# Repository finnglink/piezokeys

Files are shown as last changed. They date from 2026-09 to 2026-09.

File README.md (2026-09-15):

# PiezoKeys

A 4-key USB-MIDI keyboard using piezo discs for keystroke detection, with a laser-cut faceplate, 3D printed case, and an RGBW LED under each key. It's kinda like a stenographer's keyboard but for music: 4 keys allow you to play 15 different notes, depending on which keys you hit. You can set a root note, scale and transposition (up to +/- 2 octaves) in a small menu. 

<p align="center">
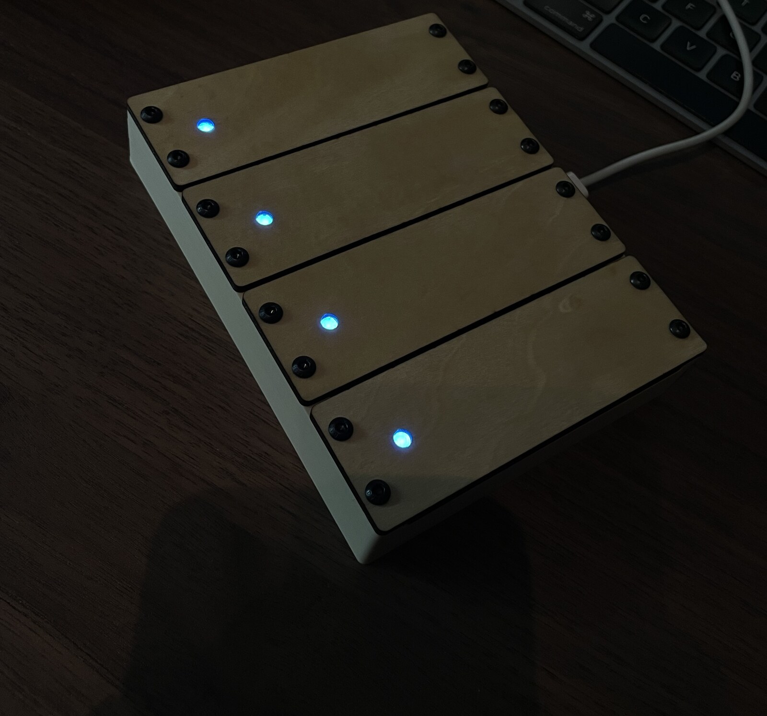
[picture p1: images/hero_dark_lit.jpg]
  
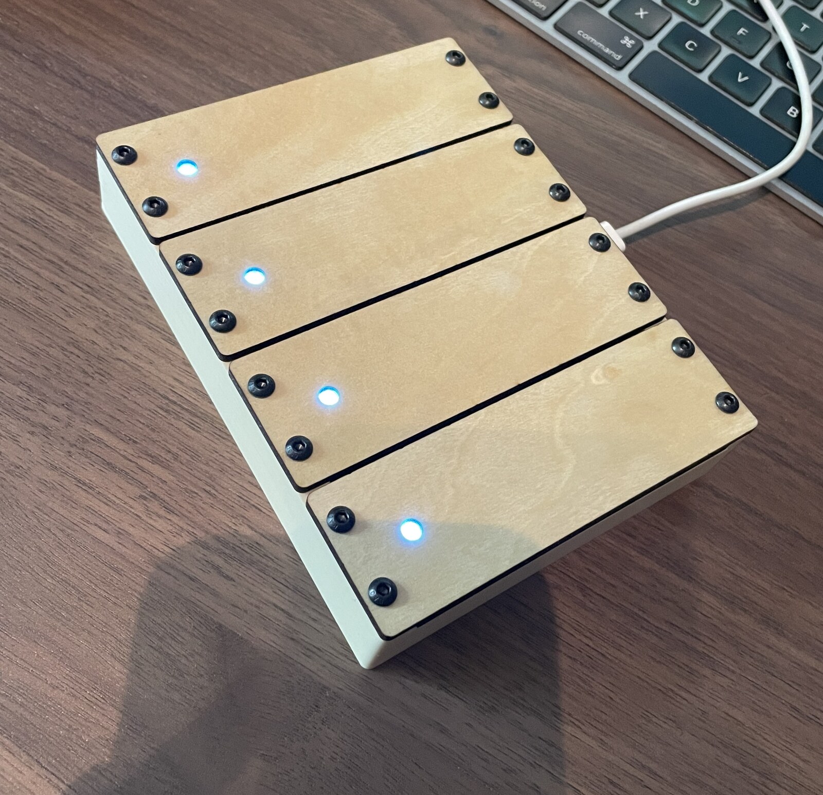
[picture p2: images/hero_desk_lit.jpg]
  
</p>

Runs on a Seeed XIAO RP2040 and shows up as a class-compliant USB MIDI device. You could also easily add a TRS MIDI Out circuit to use it with hardware synths.

### Three things you should know before you build this

**The firmware is AI-written.** I'm not a programmer, I came up with the idea, developed the keystroke and menu logic and designed the 3D models, with Claude Code doing the actual coding. It works and it's been play-tested and tuned for some time, but check the code for yourself instead of blindly trusting, and if you find something dumb, open an issue or a PR.

**Key 1 and Key 4 are less sensitive than 2 and 3.** They sit right against the outer walls of the case, which are stiffer than the inner walls, so the same tap produces a weaker signal. Software compensates with lower trigger thresholds on those two, and it's somewhat fine — but if you want to fix it properly, add one dummy/blank key on each end of the case so 1 and 4 become "inner" keys too. 

**Consider this project a work-in-progress** Some hardware bits are not 100% ideal yet, mentioned further down the build guide. Feel free to fix and improve them yourself, or do a whole different take on this concept. 

Massive credit to [**ellitone.usa**](https://www.instagram.com/ellitone.usa/) on Instagram — this whole project exists because I saw what they were doing with piezos and picked their brain about it. And their stuff looks and sounds even better than mine xD

> [!TIP]
> Join my [Discord Server](https://glnnk.art/discord) for build support and discussion.

---

## Contents

- [Bill of Materials](#bill-of-materials)
- [3D print & laser files](#3d-print--laser-files)
- [Assembly](#assembly)
- [Flashing the firmware](#flashing-the-firmware)
- [How to play it](#how-to-play-it)
- [Prototyping sketch](#prototyping-sketch)
- [License](#license)

---

## Bill of Materials

| Part | Qty | Notes |
|---|---|---|
| [USB-C breakout panel (4 or 6 pin)](https://de.aliexpress.com/item/1005005993405905.html) | 1 | Mounts in the case wall |
| [USB-C plug breakout, **male**](https://de.aliexpress.com/item/1005006026634212.html) | 1 | Remove any resistors on this one — see wiring below |
| [27–28mm piezo disc](https://de.aliexpress.com/item/1005009297969587.html) | 4 | Smaller might work too, haven't tried it |
| [SK6812 RGBW breakout, individual pixel](https://de.aliexpress.com/item/1005001527124508.html) | 4 | A cuttable strip works too, other addressable LEDs probably work with a code tweak |
| M3 heat-press insert | 16 | |
| M3x6mm screw | 16 | Longer is fine, up to 10-12mm |
| M2x6mm screw | 2 | Hold the USB-C panel jack in place |
| M2 standoff or nut | 2 | Hold the USB-C panel jack in place |
| Seeed XIAO RP2040 | 1 | Has USB-C (with MIDI capability) + 4 ADC pins, which you need all of. The RP2350 version only has 3 ADCs and won't work here |
| 620Ω resistor (600–700Ω range fine) | 4 | Pulldown for each piezo. Wider range works but you may need to retune thresholds in firmware or lose velocity sensitivity |
| Felt or rubber feet | 4 | I used 18mm felt pads meant to be put under furniture |

## 3D print & laser files

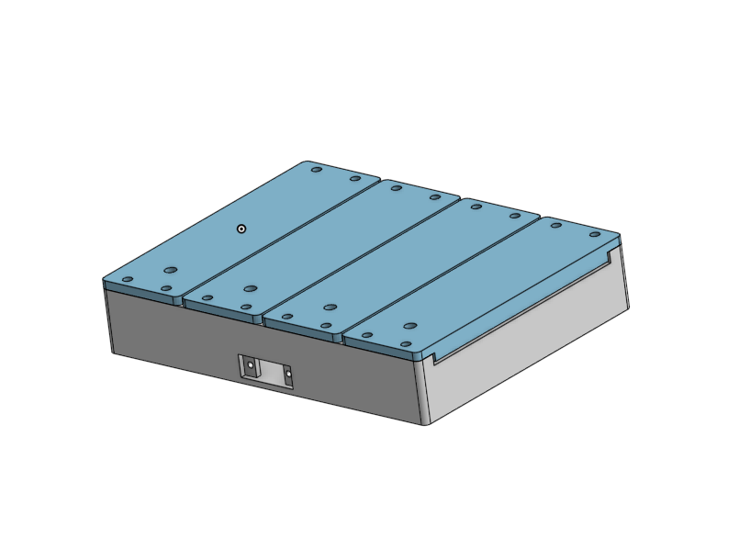
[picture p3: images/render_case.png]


Everything's in [`hardware/`](hardware):

- **`hardware/3d-print/`** — `case.stl` (mine printed fine without supports, though tree supports near the USB cutout make it a little cleaner), `led_lens.stl` × 4 (clear filament, no supports needed, print with the square recess on the buildplate), `feet_spacer.stl` (helps align whatever felt or rubber feet you have evenly) and optionally `key.stl` (the actual keys, if you don't have access to a laser. **Haven't tested these, let me know if/how well they work**). If you wanna make any changes to the actual 3D model, here is the [Onshape project](https://cad.onshape.com/documents/3bb9c38756300b0fe358b762/w/595eaf5beb0efc0a0c1872a2/e/62137f043cf174cf7afea789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) 

> [!IMPORTANT]
> If you want to build and sell this project commercially, you'll need a paid Onshape license. 

- **`hardware/laser-cut/`** — two DXF files (`piezo-keyarray-cut.dxf` for the cuts, 
`piezo-keyarray-engrave.dxf` for the engraving) plus the source `.ai` files. Cut on a Creality Falcon A1 (30×30cm bed). I had some troubles getting them aligned properly in FalconDesignSpace, make sure the engrave lines are evenly spaced between the top and bottom mounting holes on the front piece. If your laser has a smaller working area, you'll need to tile them yourself or cut in batches.

Each key is two laser-cut layers glued together: a larger front piece (with alignment lines engraved on the back) and a smaller back piece with the cutouts for the piezo and LED lens.

## Assembly

<p align="center">
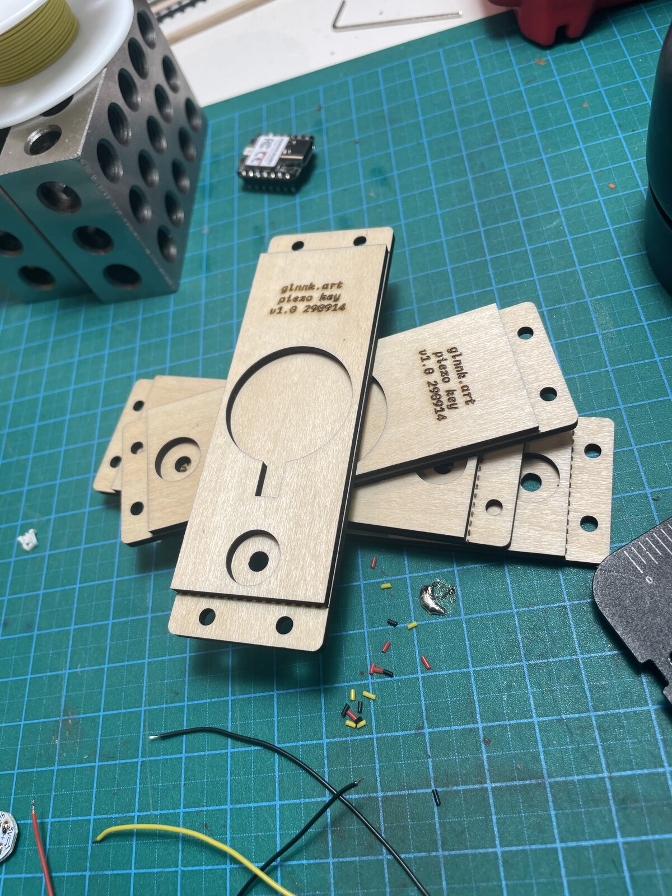
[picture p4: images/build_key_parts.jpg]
  
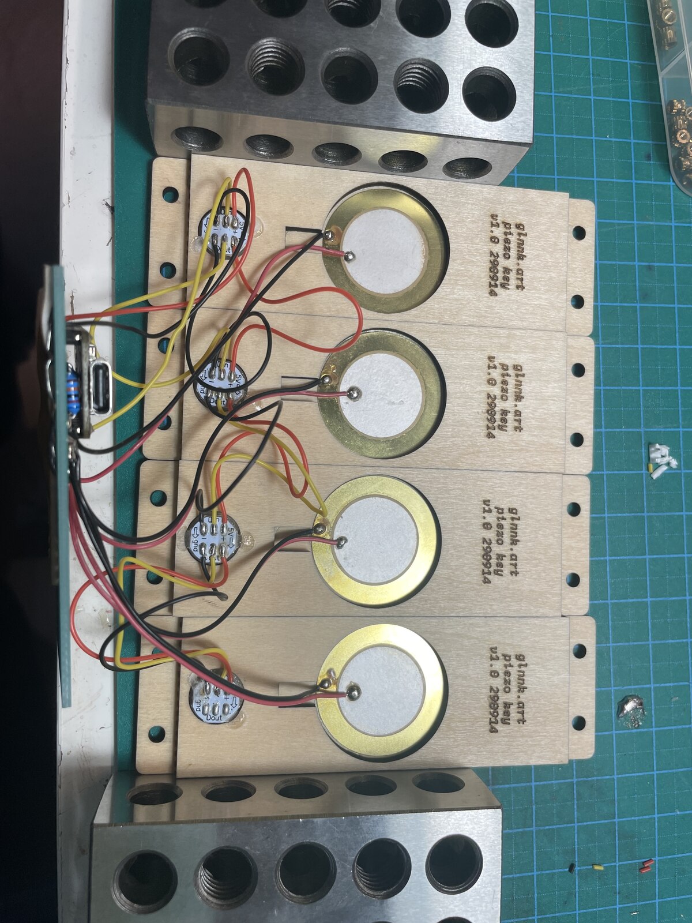
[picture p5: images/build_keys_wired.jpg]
  
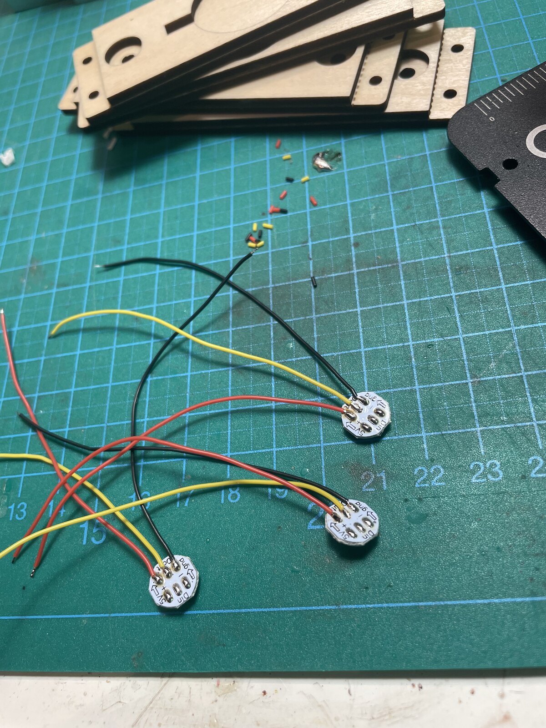
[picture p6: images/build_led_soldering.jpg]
  
</p>

**Gluing the keys:** wood glue for the two laser-cut layers of each key, with the LED lens sitting in place while it dries to keep everything aligned; leave it to dry overnight. For the LED lens itself and the LED pixels, I used Aileen's Tacky Glue, but probably any glue works; if you go with super glue, use a gel version so it fills gaps. For a next build I'd probably just hot-glue the whole thing.

**Gluing the piezos:** gel super glue, golden side down into the cutout. Lightly sand the piezo first so the glue has something to grip.

<p align="center">
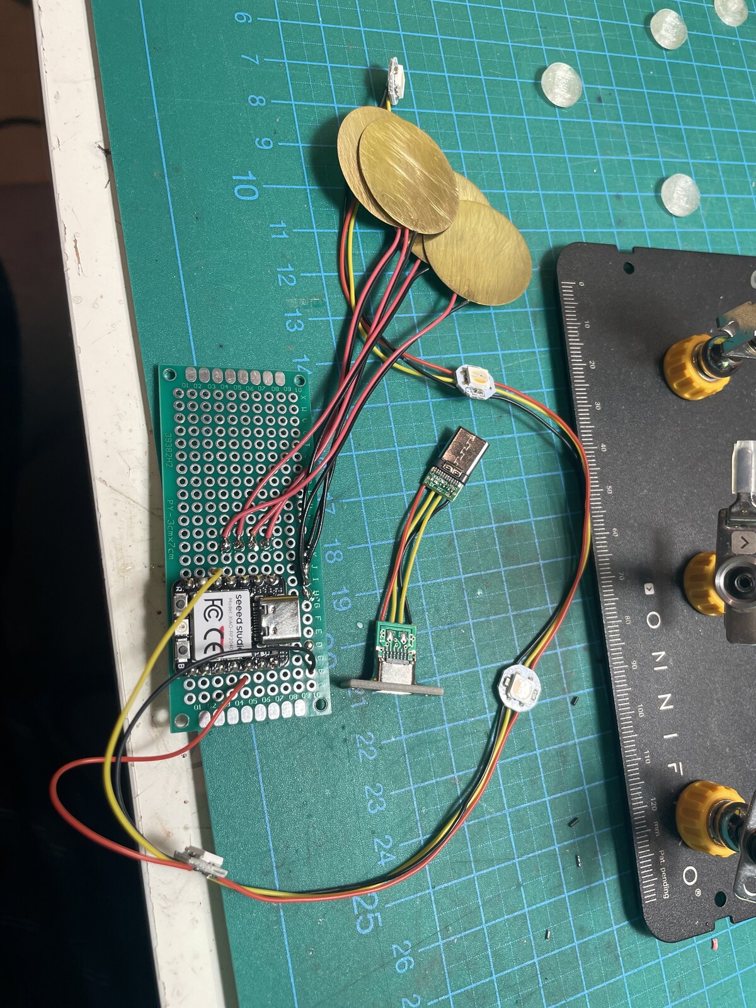
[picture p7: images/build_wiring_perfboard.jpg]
  
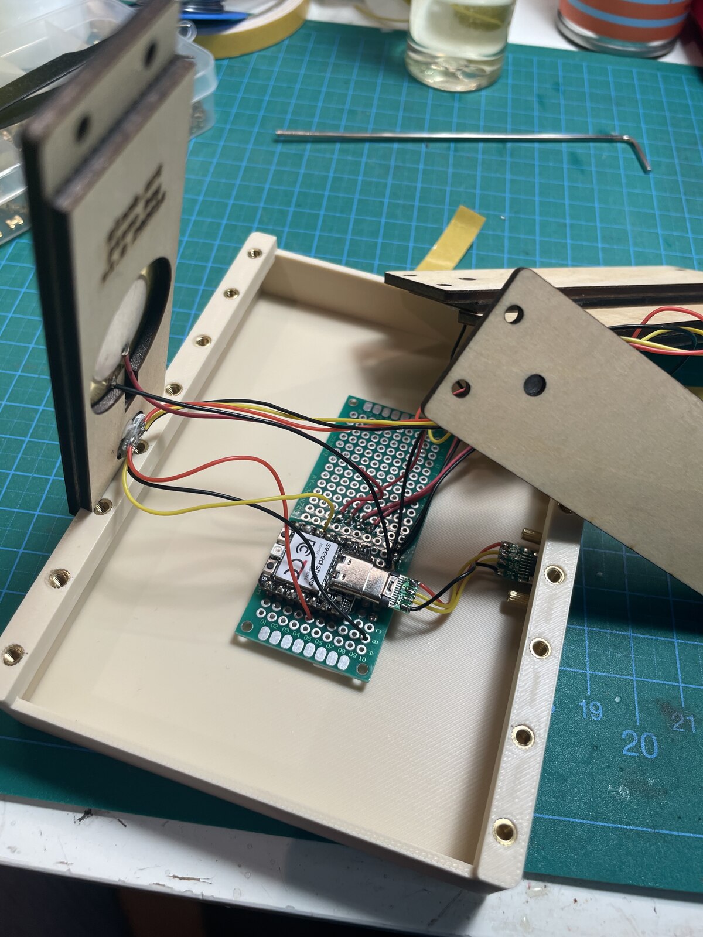
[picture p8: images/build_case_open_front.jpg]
  
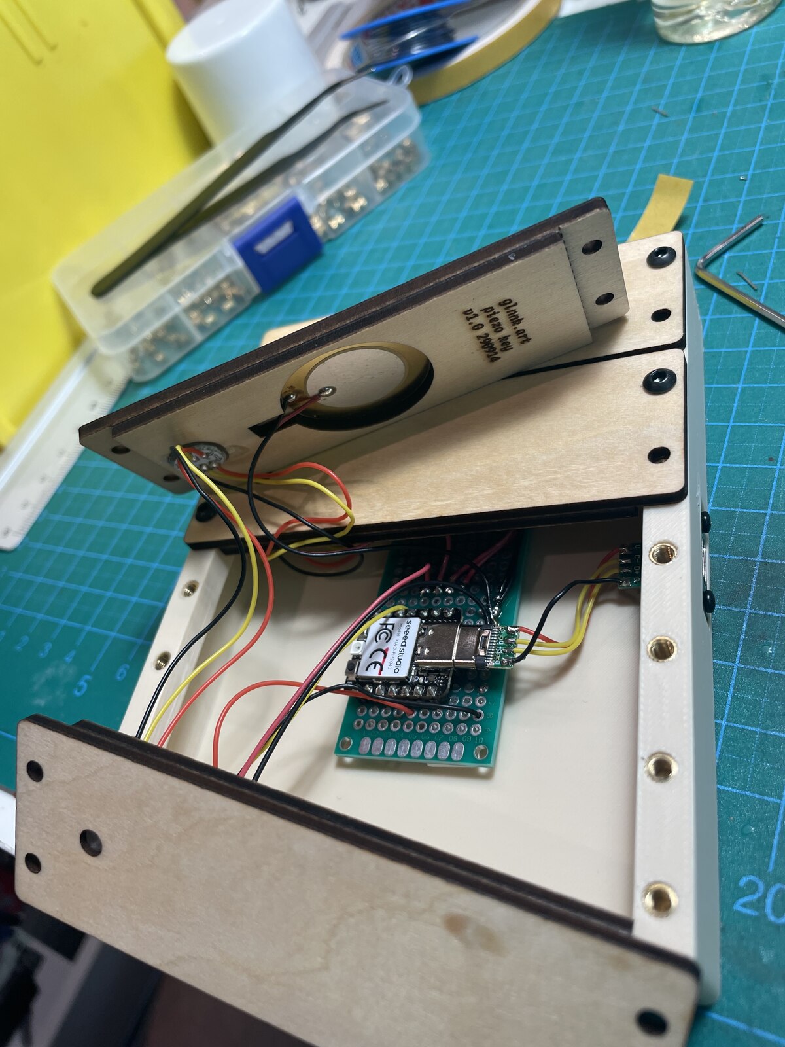
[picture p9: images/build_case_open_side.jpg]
  
</p>

**Wiring:**

- Piezos → `A0`–`A3` on the XIAO, key 1 = `A0`. Each piezo needs its resistor wired between the ADC pin and GND as a pulldown.
- LEDs are daisy-chained (Dout → Din) and the chain's data-in goes to pin `D4`. On my build the physical first LED in the chain ended up sitting on key 4, i.e. wired backwards relative to key order — I just flipped that in software (see `KEY_TO_LED` in `firmware/src/main.cpp`) instead of re-wiring. LEDs are rated for 5V but run fine off the board's 3.3V.
- USB-C: the breakout that plugs into the RP2040 has resistors on it from the factory — pull those off, keep only the two 5.1K on the panel-mount side. Wire GND–GND, 5V–5V, D+–D+, D−–D−.

<p align="center">
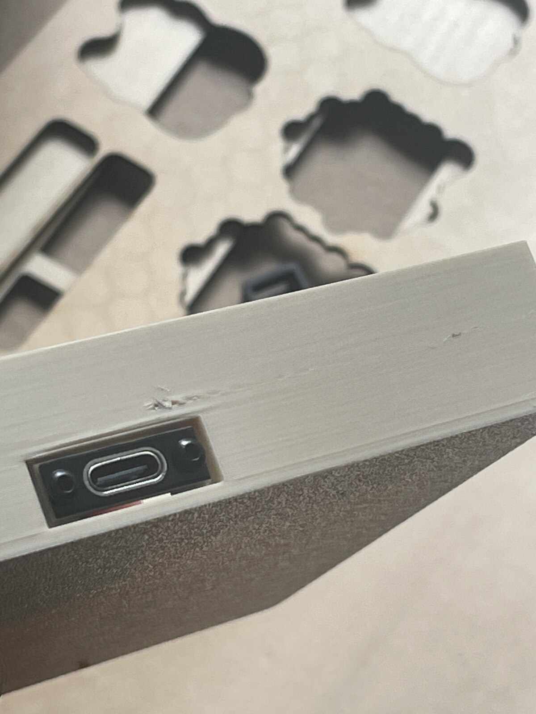
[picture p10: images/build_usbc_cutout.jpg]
  
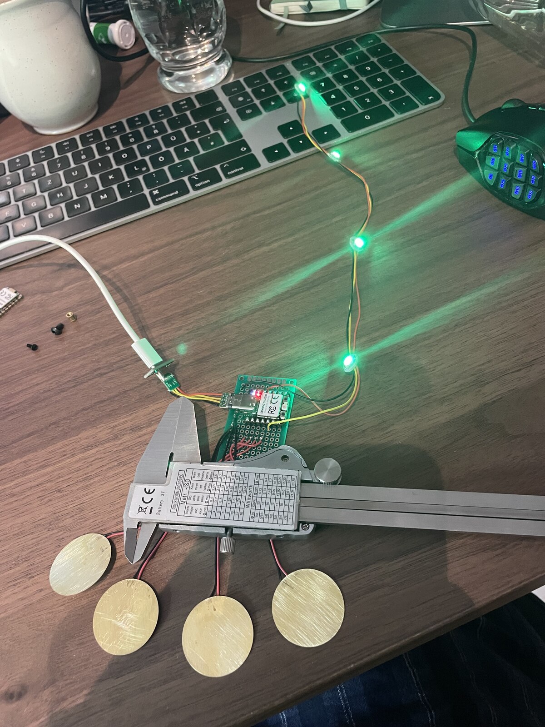
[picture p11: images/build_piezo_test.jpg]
  
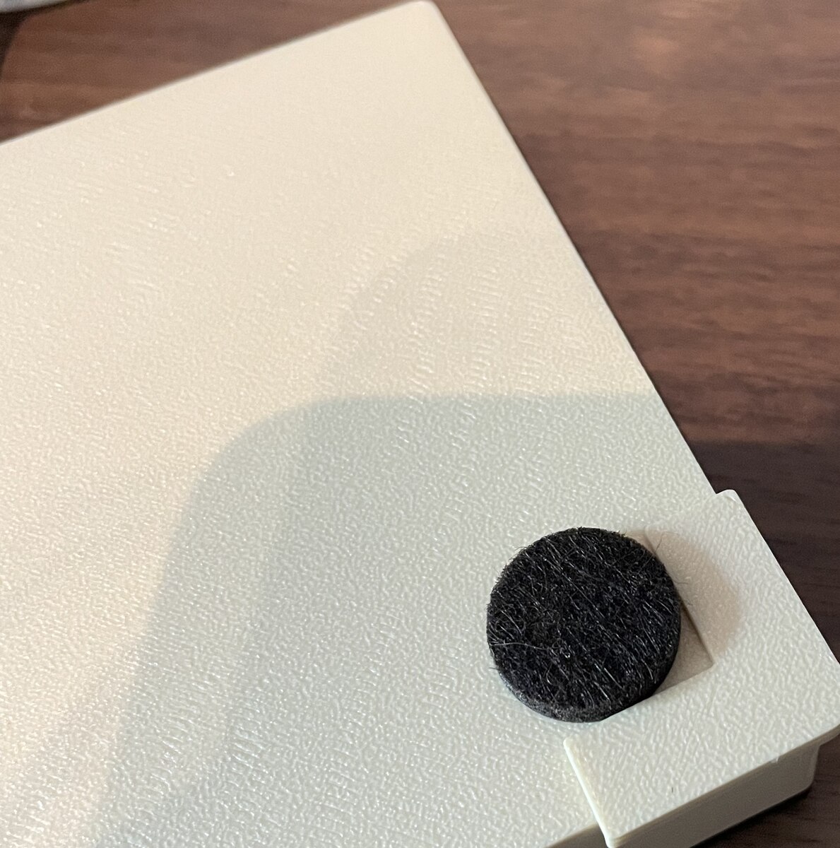
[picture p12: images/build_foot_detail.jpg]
  
</p>

Feet: felt/rubber pads glued onto the bottom, using the `feet_spacer.stl` to align them.

## Flashing the firmware

The firmware is in [`firmware/`](firmware) as a PlatformIO project (VS Code + PlatformIO extension, or the CLI — either works).

```
cd firmware
pio run              # build
pio run -t upload    # flash to the XIAO RP2040
```

It's straight Arduino framework + `Adafruit_TinyUSB` for the USB MIDI device, `FortySevenEffects/MIDI Library` for the MIDI layer, and `Adafruit NeoPixel` for the LEDs — all pulled automatically by PlatformIO, nothing to install by hand.

`firmware/src/main.cpp` is commented properly — thresholds, timing windows, the combo/hold state machine, all of it. If you're going to tune it for your own build (and you probably will, piezos are a little inconsistent), start there.

## How to play it

### One combo, one note

Every combination of the 4 keys — 15 in total — maps to one note in a 2-octave scale. Hit one key, or several at once, and you get **a single note**, not a chord (you could probably write new firmware and turn this into a chord machine of sorts). 

| Keys pressed | Scale step | Note in C major (default) |
|---|---|---|
| 1 | Root | C |
| 2 | 3rd | E |
| 1+2 | 2nd | D |
| 3 | 5th | G |
| 1+3 | 9th | D (+1 oct) |
| 2+3 | 4th | F |
| 1+2+3 | 11th | F (+1 oct) |
| 4 | 7th | B |
| **1+4** | **Octave** | **C (+1 oct)** — the "landmark" combo, outer two keys together |
| 2+4 | 10th | E (+1 oct) |
| 1+2+4 | 12th | G (+1 oct) |
| 3+4 | 6th | A |
| 1+3+4 | 13th | A (+1 oct) |
| 2+3+4 | 14th | B (+1 oct) |
| 1+2+3+4 | 15th | C (+2 oct) — everything at once, top note |

Velocity is dynamic — hit soft for quiet notes, hit hard for loud ones, curved so a light tap doesn't get buried near-silent.

### LED feedback

Each key's LED lights up when it's part of a struck combo, in a colour that encodes the *shape* of what you hit (not the pitch):

- **White** — single key
- **Blue** — adjacent pair (1+2, 2+3, 3+4)
- **Turquoise** — skip-one pair (1+3, 2+4)
- **Green** — 1+4, the octave landmark
- **Purple** — adjacent triple
- **Orange** — gapped triple
- **Red** — all 4 at once

Brightness scales with how hard you hit.

### Holding notes

Hold a combo down and the note sustains. Hit *anything*, same keys, different keys, whatever while a note's held, and it cuts the old note and starts the new one immediately, so you can play at tempo without waiting for a release to resolve first. But the new one still has to sit through the `PLAY_CHORD_WINDOW_MS` (45ms) before it actually fires, since that's how long the engine needs to see which keys you just hit. So back-to-back notes can't land much closer than 
~45ms apart, no matter how fast your fingers are.

### The menu

Tap all 4 keys together, **twice in a row** (within about 1.5 seconds) to open the settings menu. Same gesture closes it again — or wait a few seconds for the menu to close automatically.

> **The menu hack:** The most reliable way to land a clean all-4-key hit is to just smack the table near the unit twice — the thump travels through the case and triggers all 4 piezos at once. Deliberately hitting all 4 keys with your fingers at the same time is annoyingly hard; whacking the desk is not. Use this to your advantage.

Once in the menu, it uses a similar combo mechanic as playing — layer 1 picks a category per single key, layer 2 picks a value using the key combos laid out below. It auto-exits after 6 seconds of no input, and every change gets saved to flash immediately, so it survives a power-off.

**Layer 1 — pick a category (single key, LED shows category colour):**

| Key | Category | LED colour |
|---|---|---|
| 1 | Root note | Red |
| 2 | Scale | Blue |
| 3 | Transpose | Green |
| 4 | *(reserved, not assigned yet)* | Dim white |

**Layer 2 — Root** (chromatic, 12 combos):

| Keys | Note |
|---|---|
| 1 | C |
| 1+2 | C#/Db |
| 2 | D |
| 2+3 | D#/Eb |
| 3 | E |
| 3+4 | F |
| 4 | F#/Gb |
| 1+4 | G |
| 1+3 | G#/Ab |
| 2+4 | A |
| 1+2+3 | A#/Bb |
| 1+2+4 | B |

**Layer 2 — Scale:**

| Keys | Scale |
|---|---|
| 1 | Major |
| 1+2 | Natural Minor |
| 2 | Dorian |
| 2+3 | Mixolydian |
| 3 | Harmonic Minor |
| 3+4 | Melodic Minor |

**Layer 2 — Transpose:**

| Keys | Transpose |
|---|---|
| 1 | −1 octave |
| 2 | −0.5 octave |
| 3 | +0.5 octave |
| 4 | +1 octave |
| 2+3 | Reset (0) |
| 1+3 | −1.5 octave |
| 1+2 | −2 octave |
| 2+4 | +1.5 octave |
| 3+4 | +2 octave |

Selecting a new value blinks it twice to confirm, then drops you back to layer 1.

Key 4's category slot at layer 1 is currently unassigned — reserved for a future setting (maybe MIDI channel select). Pressing it in the menu does nothing right now.

## Prototyping sketch

[`prototyping/piezo_serial_test.ino`](prototyping/piezo_serial_test.ino) is a plain Arduino IDE sketch, separate from the real firmware. It just reads all 4 piezos continuously and streams the peaks to the Serial Plotter, plus runs a slow RGBW colour-cycle on the LEDs so you can confirm they're wired right. No MIDI, no combo/note logic, nothing clever — flash this first to check your wiring and get a feel for what raw piezo readings actually look like on your specific build before touching the real firmware.

## License

MIT — see [`LICENSE`](LICENSE). Build one, remix it, sell your own version, make sure to tag / show me.
> [!IMPORTANT]
> If you want to build and sell this project commercially, you'll need a paid Onshape license. 

# The End
I hope this was a fun project and you got through with ease. If you're having difficulties at any point, please reach out. You can join my [Discord Server](https://glnnk.art/discord) for support. 
I'd also love to see your creations! Tag me on Instagram or send me a photo to add here.
Check out my other stuff on [YouTube](https://glnnk.art/youtube) or [Instagram](https://instagram.com/glnnk.art).
You can [Buy me a coffee](https://www.paypal.com/paypalme/finnglink) if you've found my work helpful :)

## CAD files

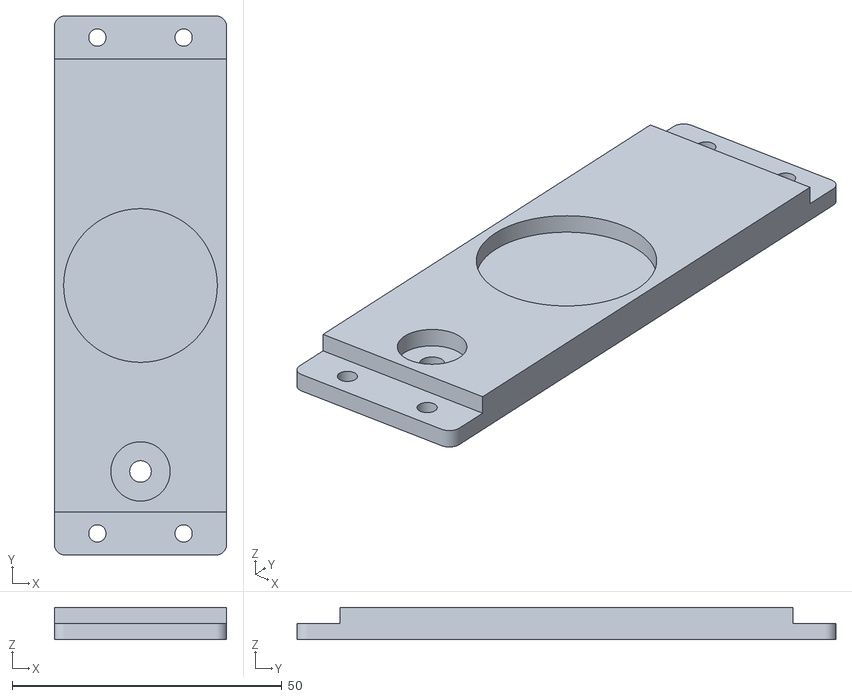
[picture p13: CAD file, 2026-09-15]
hardware/3d-print/key.stl
32.0 x 100.0 x 6.00

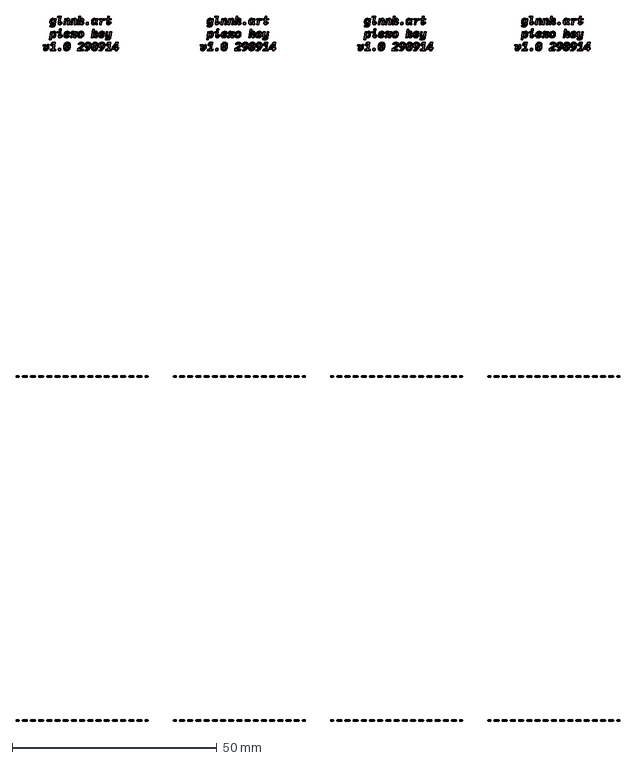
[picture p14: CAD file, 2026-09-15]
hardware/laser-cut/piezo-keyarray-engrave.dxf
147.5 x 172.2 mm

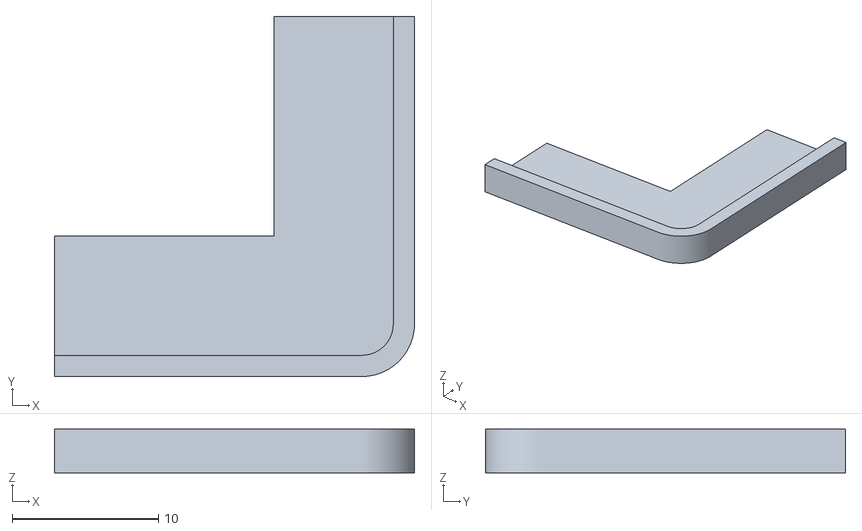
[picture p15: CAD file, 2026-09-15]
hardware/3d-print/feet_spacer.stl
24.6 x 24.6 x 3.00

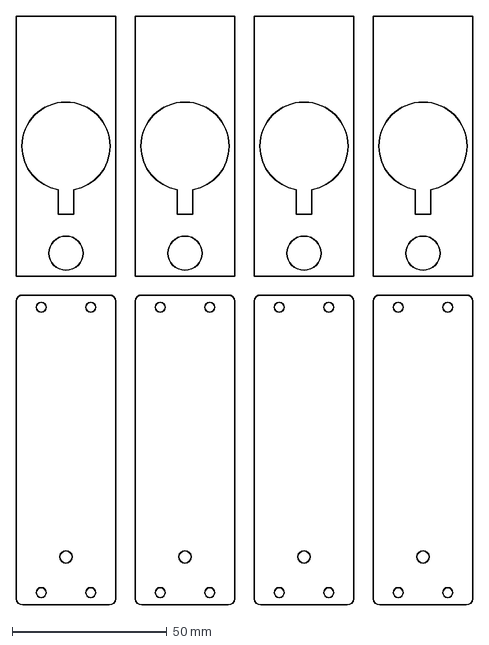
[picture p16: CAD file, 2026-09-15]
hardware/laser-cut/piezo-keyarray-cut.dxf
147.2 x 190.0 mm

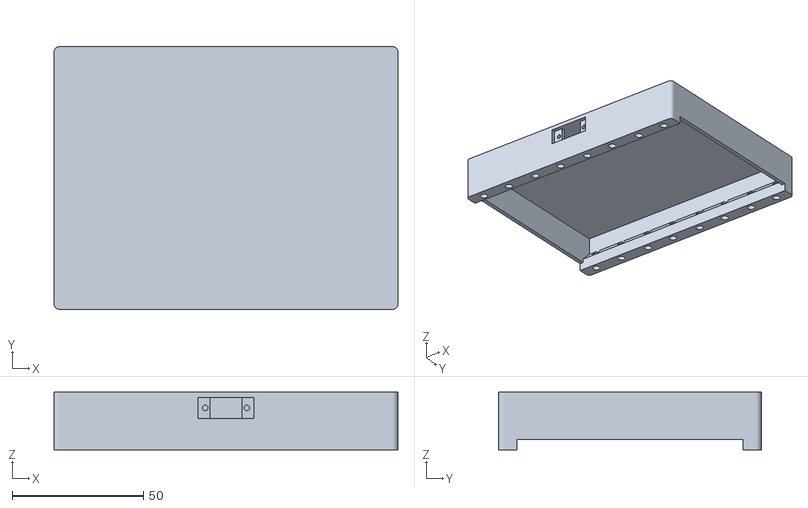
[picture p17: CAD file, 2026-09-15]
hardware/3d-print/case.stl
131.0 x 100.0 x 22.0

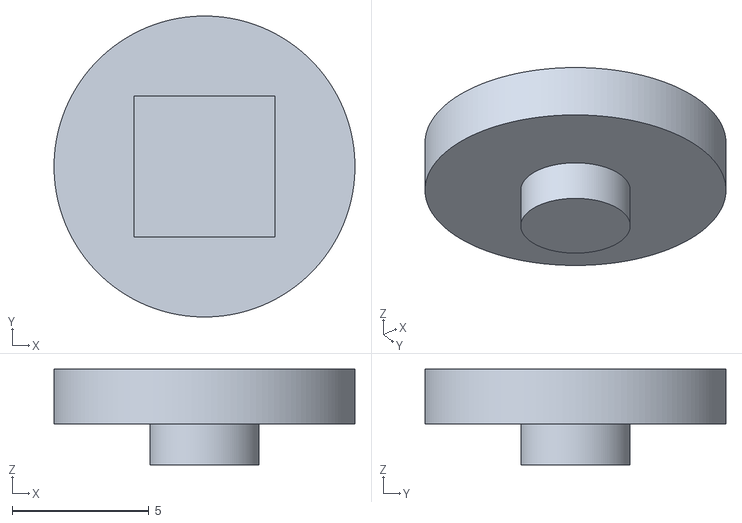
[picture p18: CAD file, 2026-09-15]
hardware/3d-print/led_lens.stl
11.0 x 11.0 x 3.50

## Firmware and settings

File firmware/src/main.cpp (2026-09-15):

// PiezoKeys -- 4-key chorded USB MIDI keyboard, Seeed XIAO RP2040
//
// Hardware: 4 piezos on A0-A3 (key1..key4), 4x SK6812 RGBW LEDs on D4,
// wired in reverse of the keys (LED 0 sits at key 4's end) -- see
// KEY_TO_LED below.
//
// Chord model: any combination of the 4 keys struck within a short window
// is one "combo" (15 possible non-empty combos of 4 keys), mapped to one
// of 15 scale degrees spanning 2 octaves -- see DEGREE_FOR_COMBO.
//
// Hold behaviour: measured piezo data shows a strike's initial peak (e.g.
// ~2290) decays to a lingering plateau of only ~76 within roughly half a
// second of a static hold -- a piezo mainly reports *change* in strain,
// which bleeds off through its bias resistor even under continued
// pressure. A held note is tracked with a real release state: once a
// chord triggers a Note On, its member channels are watched against a
// separate, much lower RELEASE_THRESHOLD (below the measured hold
// plateau but above baseline noise); once all of them dip below it for
// RELEASE_DEBOUNCE_MS, the note is actually released. This is a binary
// held/released check only -- not continuous aftertouch.
//
// Key 4 (A3) hardware note: measured data shows a persistent low-level
// hum (~55-73 counts, baseline ~26) present continuously regardless of
// activity -- not real taps. Likely a loose connection or bias-resistor
// issue. Thresholds are shared across all 4 channels for now at the
// user's request; TRIGGER_THRESHOLD_KEY4_FALLBACK below records the
// higher value (~150) that was needed to clear key 4's hum, in case it
// needs to be reinstated before the hardware is fixed.
//
// Menu: tap all 4 keys together twice (each within GESTURE_REPEAT_WINDOW_MS
// of the previous) to enter/exit. Layer 1 is 4 single-key categories
// (Root/Scale/Transpose/unassigned). Layer 2 reuses the same 15-combo
// vocabulary as play mode to pick a value within that category.

#include <Arduino.h>
#include <Adafruit_TinyUSB.h>
#include <MIDI.h>
#include <Adafruit_NeoPixel.h>
#include <EEPROM.h>
#include <math.h>

Adafruit_USBD_MIDI usb_midi;
MIDI_CREATE_INSTANCE(Adafruit_USBD_MIDI, usb_midi, MIDI);

// ---------------------------------------------------------------------
// Hardware
// ---------------------------------------------------------------------

const int PIEZO_PINS[4] = {A0, A1, A2, A3};

const int PIXEL_PIN = D4;
const int NUM_PIXELS = 4;
Adafruit_NeoPixel pixels(NUM_PIXELS, PIXEL_PIN, NEO_GRBW + NEO_KHZ800);

// LEDs are wired in reverse of the keys (pixel 0 sits at key 4's end).
const uint8_t KEY_TO_LED[4] = {3, 2, 1, 0};

// ---------------------------------------------------------------------
// Piezo sampling / chord detection tuning
// ---------------------------------------------------------------------

const uint32_t SAMPLE_INTERVAL_US = 200; // 5000 samples/sec per channel

// Shared trigger threshold across all 4 channels for now (see header note
// re: key 4's hum). TRIGGER_THRESHOLD_KEY4_FALLBACK is the previously
// measured value that safely cleared key 4's hum, kept here for reference.
// Threshold reduced ~5% from the original 90 to give softer taps and
// multi-key presses more headroom -- watch whether this is still enough
// to reliably reject noise, especially on key 4.
const int TRIGGER_THRESHOLD_DEFAULT = 85; // keys 2 and 3
// Keys 1 and 4 sit on the outer, stiffer sides of the shell and read
// consistently weaker for the same physical force. Split into separate
// per-key constants now that they've diverged: key 1 has no known noise
// problem, so it's been pushed lower still for responsiveness (its
// original-capture incidental-bump ceiling was ~48, well below this).
// Key 4 is kept higher since it has less room -- it sits close to its
// previously measured hardware hum ceiling (~73, see header note);
// TRIGGER_THRESHOLD_KEY4_FALLBACK is the old, hum-safe value to fall back
// to if false triggers resurface there.
const int TRIGGER_THRESHOLD_KEY1 = 62;
const int TRIGGER_THRESHOLD_KEY4 = 78;
const int TRIGGER_THRESHOLD_KEY4_FALLBACK = 150; // unused for now, see header note
const int TRIGGER_THRESHOLD[4] = {
  TRIGGER_THRESHOLD_KEY1, TRIGGER_THRESHOLD_DEFAULT,
  TRIGGER_THRESHOLD_DEFAULT, TRIGGER_THRESHOLD_KEY4,
};

// Retrigger detection during a hold needs a bar clearly above both (a) a
// held note's own natural pressure jitter -- real data shows a firm
// (not just resting) hold can produce transients well past the old
// 150 -- and (b) key 1's slower-rising attack, whose peak sometimes isn't
// fully captured by the initial chord window and keeps climbing past it,
// which the old lower bar misread as a brand new strike (visible as a
// low-velocity note immediately followed by a higher-velocity one).
// Raised well above ordinary medium-tap territory so only a clearly
// deliberate new hit counts -- trade-off: very soft, fast re-strikes on
// the same key while still held may not register until release instead.
const int RETRIGGER_THRESHOLD = 500;

// Retrigger checks are ignored for this long right after note-on, giving
// a slow-rising attack (key 1 especially) time to finish climbing instead
// of having its own continued rise misread as a second strike.
const uint32_t RETRIGGER_GRACE_MS = 80;

// A channel only counts toward a chord if its peak is also at least this
// fraction of the loudest channel's peak in the same window -- rejects
// crosstalk from a hard hit on a neighbouring key (worst case measured:
// ~37% crosstalk). Lowered from 0.5 to give real multi-key presses more
// slack -- the piezos aren't equally sensitive (key 1 in particular reads
// noticeably weaker than the others for the same physical force) and a
// soft double-tap's natural per-finger variance is a much larger fraction
// of its peak than a hard hit's, so the old, stricter ratio was rejecting
// genuine multi-key hits more often at low velocity or on key 1. This
// value sits just below the worst crosstalk case we measured, so very
// hard hits may occasionally register a neighbour's crosstalk as part of
// the chord -- tune back up if that becomes a real problem.
const float DOMINANCE_RATIO = 0.4f;

// Widened (was 20ms, briefly) -- multi-key detection reliability matters
// more than shaving a few ms of latency; gives fingers more room to land
// within the same window.
const uint32_t PLAY_CHORD_WINDOW_MS = 45;
const uint32_t MENU_CHORD_WINDOW_MS = 200;

const int RELEASE_THRESHOLD = 45;          // below this (all member channels) counts as released
const uint32_t RELEASE_DEBOUNCE_MS = 180;  // must stay below release threshold this long to confirm release
                                            // (widened so a brief pressure dip mid-hold doesn't end the note)
const uint32_t MIN_NOTE_DURATION_MS = 50;  // minimum audible duration even on an instant tap-release
const uint32_t MAX_HOLD_MS = 4000;         // safety cap in case release is never cleanly detected

const uint32_t REFRACTORY_MS = 150;    // per-key debounce after release, starts after note-off
const uint32_t MENU_COOLDOWN_MS = 200; // debounce after a menu selection
const uint32_t MENU_IDLE_TIMEOUT_MS = 6000; // auto-exit the menu after this long with no input

const int VELOCITY_ADC_FLOOR = 85;
const int VELOCITY_ADC_CEILING = 4095; // piezos saturate the ADC on a hard hit
const float VELOCITY_GAMMA = 0.5f;     // <1 boosts low-end response
const int MIN_VELOCITY = 10;

// Widened from 700ms -- the held first all-4 tap has to actually release
// (RELEASE_DEBOUNCE_MS + per-key REFRACTORY_MS, plus however long it takes
// to lift all 4 fingers) before the engine can even see the second tap,
// which was eating most of the old window.
const uint32_t GESTURE_REPEAT_WINDOW_MS = 1500; // max gap between the 2 all-4 taps

const float LED_MIN_BRIGHT_FRAC = 0.15f;

// ---------------------------------------------------------------------
// Note / scale / menu tables
// ---------------------------------------------------------------------

const uint8_t ROOT_BASE_NOTE = 60; // MIDI note for root's "C" at transpose 0
const uint8_t MIDI_CHANNEL = 1;

struct RGBW { uint8_t r, g, b, w; };

const RGBW COLOR_WHITE     = {0, 0, 0, 255};
const RGBW COLOR_BLUE      = {0, 0, 255, 0};
const RGBW COLOR_TURQUOISE = {0, 206, 180, 0};
const RGBW COLOR_GREEN     = {0, 255, 0, 0};
const RGBW COLOR_PURPLE    = {140, 0, 255, 0};
const RGBW COLOR_ORANGE    = {255, 90, 0, 0};
const RGBW COLOR_RED       = {255, 0, 0, 0};

const RGBW CAT_COLOR_ROOT       = {255, 0, 0, 0};
const RGBW CAT_COLOR_SCALE      = {0, 0, 255, 0};
const RGBW CAT_COLOR_TRANSPOSE  = {0, 255, 0, 0};
const RGBW CAT_COLOR_UNASSIGNED = {0, 0, 0, 40};

struct ScaleDef { const char *name; int8_t intervals[7]; };

const ScaleDef SCALE_TABLE[6] = {
  {"Major",         {0, 2, 4, 5, 7, 9, 11}},
  {"NaturalMinor",  {0, 2, 3, 5, 7, 8, 10}},
  {"Dorian",        {0, 2, 3, 5, 7, 9, 10}},
  {"Mixolydian",    {0, 2, 4, 5, 7, 9, 10}},
  {"HarmonicMinor", {0, 2, 3, 5, 7, 8, 11}},
  {"MelodicMinor",  {0, 2, 3, 5, 7, 9, 11}},
};

// combo bitmask (bit0=key1 .. bit3=key4) -> scale degree 1-15. Index 0 unused.
const uint8_t DEGREE_FOR_COMBO[16] = {
  0,  1,  3,  2,  5,  9,  4, 11,
  7,  8, 10, 12,  6, 13, 14, 15,
};

// combo bitmask -> play-mode LED color (encodes chord *shape*)
const RGBW COLOR_FOR_COMBO[16] = {
  COLOR_WHITE, // 0 unused
  COLOR_WHITE, COLOR_WHITE, COLOR_BLUE, COLOR_WHITE, COLOR_TURQUOISE, COLOR_BLUE, COLOR_PURPLE,
  COLOR_WHITE, COLOR_GREEN, COLOR_TURQUOISE, COLOR_ORANGE, COLOR_BLUE, COLOR_ORANGE, COLOR_PURPLE, COLOR_RED,
};

// combo bitmask -> chromatic root offset 0-11 (C..B), -1 = not assigned
const int8_t ROOT_FOR_COMBO[16] = {
  -1,  0,  2,  1,  4,  8,  3, 10,
   6,  7,  9, 11,  5, -1, -1, -1,
};

// combo bitmask -> index into SCALE_TABLE, -1 = not assigned
const int8_t SCALE_FOR_COMBO[16] = {
  -1,  0,  2,  1,  4, -1,  3, -1,
  -1, -1, -1, -1,  5, -1, -1, -1,
};

// combo bitmask -> transpose in semitones, INVALID_TRANSPOSE = not assigned
const int INVALID_TRANSPOSE = -1000;
const int TRANSPOSE_FOR_COMBO[16] = {
  INVALID_TRANSPOSE, -12,  -6, -24,
                   6, -18,   0, INVALID_TRANSPOSE,
                  12, INVALID_TRANSPOSE, 18, INVALID_TRANSPOSE,
                  24, INVALID_TRANSPOSE, INVALID_TRANSPOSE, INVALID_TRANSPOSE,
};

// ---------------------------------------------------------------------
// Settings persistence (RP2040 emulated EEPROM, survives reboot/power-off)
// ---------------------------------------------------------------------

const int EEPROM_SIZE = 16;
const uint8_t SETTINGS_MAGIC = 0xA5; // marks that a valid settings block was saved

struct __attribute__((packed)) PersistedSettings {
  uint8_t magic;
  int8_t rootOffset;
  int8_t scaleIndex;
  int16_t transposeSemitones;
};

// ---------------------------------------------------------------------
// Global state
// ---------------------------------------------------------------------

enum Mode { MODE_PLAY, MODE_MENU_TOP, MODE_MENU_ROOT, MODE_MENU_SCALE, MODE_MENU_TRANSPOSE };
Mode mode = MODE_PLAY;

int currentRootOffset = 0;       // 0-11
int currentScaleIndex = 0;       // index into SCALE_TABLE
int currentTransposeSemitones = 0;

enum EngineState { ENGINE_IDLE, ENGINE_CAPTURING, ENGINE_NOTE_HELD, ENGINE_MENU_COOLDOWN };
EngineState engineState = ENGINE_IDLE;

uint32_t nextSampleAt = 0;
uint32_t windowEndAt = 0;
int windowPeak[4] = {0, 0, 0, 0};

uint8_t heldCombo = 0;
uint8_t heldNoteNumber = 0;
uint32_t heldNoteOnAt = 0;
uint32_t releaseCandidateSinceMs = 0; // 0 = not currently a release candidate

uint32_t menuCooldownEndAt = 0;

uint32_t keyRefractoryUntil[4] = {0, 0, 0, 0};
bool armedForTrigger[4] = {true, true, true, true}; // must dip back below threshold before re-triggering

uint8_t allFourTapCount = 0;
uint32_t lastAllFourTapAt = 0;

uint32_t lastMenuActivityAt = 0;

// ---------------------------------------------------------------------
// Small utilities
// ---------------------------------------------------------------------

uint32_t packRGBW(RGBW c) { return pixels.Color(c.r, c.g, c.b, c.w); }

void clearAllLEDs() {
  for (int i = 0; i < NUM_PIXELS; i++) pixels.setPixelColor(i, 0);
  pixels.show();
}

void loadSettings() {
  EEPROM.begin(EEPROM_SIZE);
  PersistedSettings s;
  EEPROM.get(0, s);
  if (s.magic == SETTINGS_MAGIC) {
    currentRootOffset = s.rootOffset;
    currentScaleIndex = s.scaleIndex;
    currentTransposeSemitones = s.transposeSemitones;
    Serial.println("Settings loaded from flash");
  }
}

void saveSettings() {
  PersistedSettings s;
  s.magic = SETTINGS_MAGIC;
  s.rootOffset = (int8_t)currentRootOffset;
  s.scaleIndex = (int8_t)currentScaleIndex;
  s.transposeSemitones = (int16_t)currentTransposeSemitones;
  EEPROM.put(0, s);
  EEPROM.commit();
}

// Blink the given combo's LED pattern on/off `times` times, in `color` --
// used to confirm a menu selection actually took.
void blinkCombo(RGBW color, uint8_t combo, int times) {
  for (int rep = 0; rep < times; rep++) {
    clearAllLEDs();
    delay(120);
    for (int i = 0; i < 4; i++) {
      if (combo & (1 << i)) pixels.setPixelColor(KEY_TO_LED[i], packRGBW(color));
    }
    pixels.show();
    delay(180);
  }
  clearAllLEDs();
  delay(100);
}

void startMenuCooldown(uint32_t nowMs) {
  menuCooldownEndAt = nowMs + MENU_COOLDOWN_MS;
  engineState = ENGINE_MENU_COOLDOWN;
}

void releaseHeldNote(uint32_t nowMs) {
  MIDI.sendNoteOff(heldNoteNumber, 0, MIDI_CHANNEL);
  for (int i = 0; i < 4; i++) {
    if (heldCombo & (1 << i)) {
      pixels.setPixelColor(KEY_TO_LED[i], 0);
      keyRefractoryUntil[i] = nowMs + REFRACTORY_MS;
    }
  }
  pixels.show();
  Serial.print("NOTE OFF note="); Serial.println(heldNoteNumber);
  engineState = ENGINE_IDLE;
  releaseCandidateSinceMs = 0;
}

float velocityFraction(int peak) {
  float frac = (float)(peak - VELOCITY_ADC_FLOOR) / (float)(VELOCITY_ADC_CEILING - VELOCITY_ADC_FLOOR);
  frac = constrain(frac, 0.0f, 1.0f);
  return powf(frac, VELOCITY_GAMMA);
}

uint8_t peakToVelocity(int peak) {
  float shaped = velocityFraction(peak);
  int vel = MIN_VELOCITY + (int)roundf(shaped * (127 - MIN_VELOCITY));
  return (uint8_t)constrain(vel, 1, 127);
}

uint32_t scaleColor(RGBW c, float frac) {
  float b = LED_MIN_BRIGHT_FRAC + frac * (1.0f - LED_MIN_BRIGHT_FRAC);
  return pixels.Color((uint8_t)(c.r * b), (uint8_t)(c.g * b), (uint8_t)(c.b * b), (uint8_t)(c.w * b));
}

int degreeToSemitoneOffset(int degree) {
  int octave = (degree - 1) / 7;
  int idx = (degree - 1) % 7;
  return 12 * octave + SCALE_TABLE[currentScaleIndex].intervals[idx];
}

uint8_t comboForRootOffset(int offset) {
  for (int c = 1; c <= 15; c++) if (ROOT_FOR_COMBO[c] == offset) return (uint8_t)c;
  return 0;
}

uint8_t comboForScaleIndex(int idx) {
  for (int c = 1; c <= 15; c++) if (SCALE_FOR_COMBO[c] == idx) return (uint8_t)c;
  return 0;
}

uint8_t comboForTranspose(int semis) {
  for (int c = 1; c <= 15; c++) if (TRANSPOSE_FOR_COMBO[c] == semis) return (uint8_t)c;
  return 0;
}

void hsvToRgb(float h, uint8_t &r, uint8_t &g, uint8_t &b) {
  float c = 1.0f;
  float x = 1.0f - fabsf(fmodf(h / 60.0f, 2.0f) - 1.0f);
  float rf, gf, bf;
  if (h < 60)       { rf = c; gf = x; bf = 0; }
  else if (h < 120) { rf = x; gf = c; bf = 0; }
  else if (h < 180) { rf = 0; gf = c; bf = x; }
  else if (h < 240) { rf = 0; gf = x; bf = c; }
  else if (h < 300) { rf = x; gf = 0; bf = c; }
  else              { rf = c; gf = 0; bf = x; }
  r = (uint8_t)(rf * 255);
  g = (uint8_t)(gf * 255);
  b = (uint8_t)(bf * 255);
}

// ---------------------------------------------------------------------
// Menu
// ---------------------------------------------------------------------

void showMenuTopLEDs() {
  pixels.setPixelColor(KEY_TO_LED[0], packRGBW(CAT_COLOR_ROOT));
  pixels.setPixelColor(KEY_TO_LED[1], packRGBW(CAT_COLOR_SCALE));
  pixels.setPixelColor(KEY_TO_LED[2], packRGBW(CAT_COLOR_TRANSPOSE));
  pixels.setPixelColor(KEY_TO_LED[3], packRGBW(CAT_COLOR_UNASSIGNED));
  pixels.show();
}

// Brief blocking flash of the category color (all 4), then settles to
// showing the current value as the lit-LED pattern of its combo -- the
// same pattern you'd press to select it.
void showMenuPage(RGBW color, uint8_t currentCombo) {
  for (int i = 0; i < NUM_PIXELS; i++) pixels.setPixelColor(i, packRGBW(color));
  pixels.show();
  delay(150);
  clearAllLEDs();
  for (int i = 0; i < 4; i++) {
    if (currentCombo & (1 << i)) pixels.setPixelColor(KEY_TO_LED[i], packRGBW(color));
  }
  pixels.show();
}

void toggleMenu() {
  if (mode == MODE_PLAY) {
    mode = MODE_MENU_TOP;
    lastMenuActivityAt = millis();
    showMenuTopLEDs();
    Serial.println("MENU enter");
  } else {
    mode = MODE_PLAY;
    clearAllLEDs();
    Serial.println("MENU exit");
  }
}
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
void loop() {
#ifdef TINYUSB_NEED_POLLING_TASK
  TinyUSBDevice.task();
#endif
  MIDI.read();

  uint32_t nowUs = micros();
  if (nowUs >= nextSampleAt) {
    nextSampleAt = nowUs + SAMPLE_INTERVAL_US;
    int sample[4];
    for (int i = 0; i < 4; i++) sample[i] = analogRead(PIEZO_PINS[i]);

    // A channel only re-arms once it's actually dropped back below its own
    // trigger threshold -- regardless of how long that takes. Without this,
    // a slow-decaying key (key 1 especially) can still read above its own
    // (now quite low) threshold when REFRACTORY_MS expires, and gets
    // misread as a brand new hit from IDLE even though nothing new happened.
    for (int i = 0; i < 4; i++) {
      if (sample[i] < TRIGGER_THRESHOLD[i]) armedForTrigger[i] = true;
    }

    uint32_t nowMs = millis();

    if (engineState == ENGINE_IDLE) {
      for (int i = 0; i < 4; i++) {
        if (sample[i] >= TRIGGER_THRESHOLD[i] && nowMs >= keyRefractoryUntil[i] && armedForTrigger[i]) {
          for (int c = 0; c < 4; c++) windowPeak[c] = sample[c];
          uint32_t windowMs = (mode == MODE_PLAY) ? PLAY_CHORD_WINDOW_MS : MENU_CHORD_WINDOW_MS;
          windowEndAt = nowMs + windowMs;
          engineState = ENGINE_CAPTURING;
          break;
        }
      }
    } else if (engineState == ENGINE_CAPTURING) {
      for (int c = 0; c < 4; c++) if (sample[c] > windowPeak[c]) windowPeak[c] = sample[c];
      if (nowMs >= windowEndAt) finalizeChord(nowMs);
    } else if (engineState == ENGINE_NOTE_HELD) {
      // A fresh, full-strength hit on ANY key -- the same key(s) already
      // held, a different key, or a whole new combo -- means the user
      // wants to play something new right now. Cut the held note short
      // immediately and start capturing the new hit, instead of waiting
      // for the current note's release to resolve first (which can take
      // a while, especially on key 1) -- needed to actually play at tempo.
      // A held key still needs the higher RETRIGGER_THRESHOLD bar (hold
      // jitter / this same hit's own decay stays well below it, so a
      // crossing there is unambiguous); a different, not-currently-held
      // key just needs its own normal trigger threshold, same as from idle.
      bool retrigger = false;
      if ((nowMs - heldNoteOnAt) >= RETRIGGER_GRACE_MS) {
        for (int i = 0; i < 4; i++) {
          int bar = (heldCombo & (1 << i)) ? RETRIGGER_THRESHOLD : TRIGGER_THRESHOLD[i];
          if (sample[i] >= bar) { retrigger = true; break; }
        }
      }

      if (retrigger) {
        releaseHeldNote(nowMs);
        for (int c = 0; c < 4; c++) windowPeak[c] = sample[c];
        uint32_t windowMs = (mode == MODE_PLAY) ? PLAY_CHORD_WINDOW_MS : MENU_CHORD_WINDOW_MS;
        windowEndAt = nowMs + windowMs;
        engineState = ENGINE_CAPTURING;
      } else {
        bool allBelowRelease = true;
        for (int i = 0; i < 4; i++) {
          if ((heldCombo & (1 << i)) && sample[i] >= RELEASE_THRESHOLD) { allBelowRelease = false; break; }
        }
        if (allBelowRelease) {
          if (releaseCandidateSinceMs == 0) releaseCandidateSinceMs = nowMs;
        } else {
          releaseCandidateSinceMs = 0;
        }

        bool debounceOk = releaseCandidateSinceMs != 0 && (nowMs - releaseCandidateSinceMs) >= RELEASE_DEBOUNCE_MS;
        bool minDurationOk = (nowMs - heldNoteOnAt) >= MIN_NOTE_DURATION_MS;
        bool maxHoldExceeded = (nowMs - heldNoteOnAt) >= MAX_HOLD_MS;

        if ((debounceOk && minDurationOk) || maxHoldExceeded) releaseHeldNote(nowMs);
      }
    }
  }

  uint32_t nowMs = millis();
  if (engineState == ENGINE_MENU_COOLDOWN && nowMs >= menuCooldownEndAt) {
    engineState = ENGINE_IDLE;
  }

  if (mode != MODE_PLAY && (nowMs - lastMenuActivityAt) >= MENU_IDLE_TIMEOUT_MS) {
    toggleMenu(); // idle timeout: drop back to play mode
  }
}

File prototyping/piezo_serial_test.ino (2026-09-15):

// RP2040 + 4 piezo discs on A0-A3 -> continuous readout for Arduino IDE Serial Plotter
// Also drives 4x SK6812 RGBW pixels on D4, smoothly cycling through R/G/B/W.
//
// Wiring (important for RP2040 - its ADC pins are only 0-3.3V tolerant,
// unlike classic AVR Arduinos which clamp overvoltage internally):
//   Piezo lead 1 -> A0 / A1 / A2 / A3
//   Piezo lead 2 -> GND
//   1M ohm resistor across each piezo's two leads (bias/bleed resistor -
//     keeps the reading centered near 0 instead of floating, and
//     dampens the voltage spike from a hard tap)
//   Optional but recommended clamp diodes (e.g. 1N4148) to protect each ADC
//     pin from voltage spikes outside 0-3.3V:
//       anode -> Ax,  cathode -> 3V3   (clips positive spikes above 3.3V)
//       anode -> GND, cathode -> Ax    (clips negative spikes below 0V)
//
//   SK6812 RGBW data in -> D4 (through a ~330-470 ohm series resistor is
//     recommended), pixel VDD -> 5V, GND -> GND.

#include <Adafruit_NeoPixel.h>

const int PIEZO_PINS[4] = {A0, A1, A2, A3};

// Sample the sensors fast so sharp taps aren't missed between reads...
const uint32_t SAMPLE_INTERVAL_US = 200;   // 0.2ms -> 5000 samples/sec per channel

// ...but only push values to Serial at a rate a human (and the Serial
// Plotter) can actually watch. Between sends we keep the highest sample
// seen per channel, so fast spikes still show up even though the plot
// itself is slow.
const uint32_t PLOT_INTERVAL_MS = 33;      // ~30 updates/sec

uint32_t nextSampleAt = 0;
uint32_t nextPlotAt = 0;
int peaks[4] = {0, 0, 0, 0};

// --- SK6812 RGBW pixels -----------------------------------------------

const int PIXEL_PIN = D4;
const int NUM_PIXELS = 4;
const uint8_t PIXEL_BRIGHTNESS = 51; // 20% of 255

Adafruit_NeoPixel pixels(NUM_PIXELS, PIXEL_PIN, NEO_GRBW + NEO_KHZ800);

struct RGBW {
  uint8_t r, g, b, w;
};

// Order the cycle passes through: Red -> Green -> Blue -> White -> (back to Red)
const RGBW CYCLE_COLORS[4] = {
  {255, 0,   0,   0},
  {0,   255, 0,   0},
  {0,   0,   255, 0},
  {0,   0,   0,   255},
};

const uint32_t COLOR_CYCLE_MS = 8000;               // full 4-color loop duration
const uint32_t PIXEL_UPDATE_INTERVAL_MS = 20;        // ~50 updates/sec, plenty smooth
uint32_t nextPixelUpdateAt = 0;

uint8_t lerp8(uint8_t from, uint8_t to, float frac) {
  return from + (int)((to - from) * frac + 0.5f);
}

void updatePixels() {
  const uint32_t segmentMs = COLOR_CYCLE_MS / 4;
  uint32_t t = millis() % COLOR_CYCLE_MS;
  int segment = t / segmentMs;
  float frac = (t % segmentMs) / (float)segmentMs;

  const RGBW &from = CYCLE_COLORS[segment];
  const RGBW &to = CYCLE_COLORS[(segment + 1) % 4];

  uint32_t color = pixels.Color(
    lerp8(from.r, to.r, frac),
    lerp8(from.g, to.g, frac),
    lerp8(from.b, to.b, frac),
    lerp8(from.w, to.w, frac)
  );

  for (int i = 0; i < NUM_PIXELS; i++) {
    pixels.setPixelColor(i, color);
  }
  pixels.show();
}

// ------------------------------------------------------------------------

void setup() {
  Serial.begin(115200);
  analogReadResolution(12); // RP2040 ADC is 12-bit (0-4095)

  pixels.begin();
  pixels.setBrightness(PIXEL_BRIGHTNESS);
  pixels.show(); // all off until the first updatePixels() call
}

void loop() {
  uint32_t nowUs = micros();
  if (nowUs >= nextSampleAt) {
    nextSampleAt = nowUs + SAMPLE_INTERVAL_US;
    for (int i = 0; i < 4; i++) {
      int value = analogRead(PIEZO_PINS[i]);
      if (value > peaks[i]) peaks[i] = value;
    }
  }

  uint32_t nowMs = millis();

  if (nowMs >= nextPlotAt) {
    nextPlotAt = nowMs + PLOT_INTERVAL_MS;

    // "Ceiling" and "Floor" are constant at the ADC's true 0-4095 range.
    // Plotting them alongside the peaks pins the graph's autoscale to the
    // full range, so you can actually see how much headroom you're using
    // instead of the plot rescaling to fit whatever just came in.
    Serial.print("Peak0:");
    Serial.print(peaks[0]);
    Serial.print(",Peak1:");
    Serial.print(peaks[1]);
    Serial.print(",Peak2:");
    Serial.print(peaks[2]);
    Serial.print(",Peak3:");
    Serial.print(peaks[3]);
    Serial.print(",Ceiling:4095,Floor:0");
    Serial.println();

    for (int i = 0; i < 4; i++) peaks[i] = 0; // reset the hold for the next window
  }

  if (nowMs >= nextPixelUpdateAt) {
    nextPixelUpdateAt = nowMs + PIXEL_UPDATE_INTERVAL_MS;
    updatePixels();
  }
}
